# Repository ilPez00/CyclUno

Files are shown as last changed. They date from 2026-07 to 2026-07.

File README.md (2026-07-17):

# CyclUno

Cyclops dev unit on an Arduino Uno — deck edition. Two jobs, one breadboard:

1. **Cyclops dev unit** — the wearable product at breadboard scale: joystick
   + buttons + SPI TFT + LEDs, wired to the brain over USB serial. No WiFi/BT —
   the cable substitutes the radio while exercising the exact same v2 frame
   protocol and the exact same brain pipeline (transcriber → extractor →
   notes → HUD frames).
2. **aion control deck** — the physical console for the
   [aion](https://github.com/ilPez00/aion) cockpit TUI: two thumb
   joysticks, four face buttons, a mode switch. In AION mode the deck
   navigates the cockpit one-handed; in APP mode it becomes a Linux gamepad
   (uinput "CyclUno Pad") driving whatever program aion spawned. The SPI TFT
   mirrors aion status. Jarvis, but with detents.

The cyclops brain side (SerialLink, `demo_cycluno.py`, bash TUI) lives in the
[cyclops](https://github.com/ilPez00/cyclops-wearable) repo; the aion deck
host side lives in aion (`src/aion/deck/`). This repo is the firmware only.
Wire protocol: `include/cyclops_shared.h` (kept in sync with cyclops
`firmware/lib/cyclops_shared`); input-event payloads: `include/deck.h`
(pinned byte-for-byte to aion's `deck/protocol.py` by `test/test_deck.cpp`).

## Why an Uno when the XIAO exists
- Input bring-up without risking the wearable board.
- The ATmega328P's 2 KB SRAM forces the lean-HUD discipline
  (`sizeof(UnoHud)` gated < 400 B by the host tests).
- Anything proven here (input handling, frame flow, pipeline) transfers
  upstream unchanged, because the wire protocol is shared.

## Wiring

deck wiring

Full assembly guide — BOM, step-by-step order (each step leaves a working
unit), rules the wiring relies on, troubleshooting: **[docs/WIRING.md](docs/WIRING.md)**.

Quick pin map: confirmed 128×128 SPI TFT (ST7735, 1.44 in)
TFT D11 MOSI/SDA · D13 SCK/SCL · D10 CS · D9 DC · RES→3.3V via 10k · BL→3.3V/VCC per module
joy1 A0/A1+D4 · joy2 A2/A3+D8 · B D5 · MODE D2 · X D3 · Y D12 · LEDs D6/D7 ·
APP LED A4 (external; D13 is now TFT clock). Everything beyond joy1 + B is optional: unwired pins
read as unpressed (internal pullups) and the unit degrades to the original
single-stick HUD.

console layout

### Controls — AION mode (A4 LED off)
Local HUD: **stick 1 up/down** scrolls · **stick 1 right / SW** = A (REC
toggle on HOME, select in MENU) · **stick 1 left / button B** = menu/back.
Forwarded to the aion cockpit: **joy2** = navigate workspaces · **X** = pause ·
**Y** = cancel · **stick 2 click** = activate.

### Controls — APP mode (MODE button toggles, A4 LED on)
The deck is a gamepad: **stick 2** = analog axes · **A/B/X/Y + both stick
clicks + wheel click** = buttons · **joy2** = navigate. aion exposes it as a
uinput device named "CyclUno Pad"; spawn a program (`run app mpv …`) and play.

Keep both sticks at rest during boot — those readings become the calibrated
centers. If a direction feels flipped for your module's mounting, set
`JOY_FLIP_Y` / `JOY_FLIP_X` in `src/main.cpp`.

## Build + flash
```
make test     # host gate: HUD logic + joystick nav + deck logic, plain g++
make build    # pio run -e cycluno
make flash    # pio run -e cycluno -t upload
```

## Run the wired brain
From the cyclops repo:
```
python3 demo_cycluno.py       # auto-picks /dev/ttyACM*|ttyUSB*
```
Press **A** on the unit: the driver "transcribes" the next prerecorded take
through the real pipeline and streams the extracted notes back as NOTE frames
onto the SPI TFT.

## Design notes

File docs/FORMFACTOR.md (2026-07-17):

# CyclUno — Form Factor Spec (aion control deck)

Design thesis for the physical enclosure. Grounded in the aion cockpit nav
model (see `aion/src/aion/`) and HCI precedent for split dual-thumbstick
one-handed consoles (Steam Controller / Xbox Adaptive / FragChuck lineage).

## 1. What the deck IS

CyclUno is the **aion control deck**: a two-thumb, one-handed cockpit console.
- **joy1 (left thumb)** = primary navigation: up/down scroll lists, left/right (or
  SW click) = switch workspace (13 workspaces, wraps modulo).
- **joy2 (right thumb)** = activate/context in AION mode; analog axes in APP mode
  (uinput "CyclUno Pad" gamepad).
- **Buttons**: A=activate/REC, B=back/menu, MODE=AION⇄APP toggle, X/Y=context.
- **OLED (128×128, 16×16 text grid)** = status compass: always show WORKSPACE
  NAME + 1-line context (top row), since 13 workspaces need constant orientation.
- **MODE** must be a physical slide/rocker with detent, NOT a held button
  (context flip you can feel without looking).
  **RESOLVED (2026-07-17, research-backed):** part = **MTS-103** mini toggle,
  SPDT ON-OFF-ON (AION/OFF/APP), panel-mount M6×0.75 bushing + 2.4 mm keyway
  (see docs/reference/palm-deck-research.md §4). Solder-lug part — the
  breadboard dev unit keeps the momentary button on D2. Firmware 3-pos read
  (D2 + A5 INPUT_PULLUP, center-off = neither low) is DEFERRED: mode codes are
  pinned byte-for-byte to aion's deck/protocol.py (0=AION 1=APP only), so an
  OFF state is a cross-repo protocol change to coordinate with aion first.

## 2. Ergonomic rules (from HCI precedent)

1. **Offset symmetric thumbsticks, not collinear.** Steam/Xbox layout is proven
   best for simultaneous dual-thumb use without hand cramp. Two HW-504 sticks
   sit at ~45° offset (left-lower, right-upper), like a Steam Controller —
   NOT side-by-side flat.
2. **Thumbs own the whole interaction.** joy1 does list-scroll AND workspace-switch;
   it needs a click (SW=activate) + 4 directions. No finger-reassignment mid-flow.
3. **Mode = detent rocker.** AION⇄APP is a context flip; a 3-pos rocker
   (AION / OFF / APP) you feel, prevents accidental gamepad-vs-cockpit mode.
4. **OLED as status compass, not a screen.** 128×128 = 16×16 text. Top row =
   workspace + context. This is the "where am I" anchor.
5. **One-handed grip envelope.** Fits a relaxed palm, both thumbs on sticks.
   Target ~90–110mm wide, ~60–70mm deep, contoured to palm.

## 3. Highest-frequency action = workspace switch

13 workspaces (desktop, models, tasks, agent, memory, vault, sys, hermes,
skills, projects, term, swarm, settings). joy1-left/right → `switch_workspace`
is the most-used nav action — keep it on the PRIMARY thumb, low-friction,
non-mode. Current protocol already maps joy1 L/R → switch_workspace. **Keep it.**

## 4. Recommended form factor — TIER A: "Palm Deck"

Evolve the enclosure from a rectangular breadboard box into a contoured controller:

- Contoured underside (fits palm); flat-ish top face.
- **Offset thumbsticks**: left stick lower-left ~30° rake, right stick upper-right.
- **MODE rocker** (3-pos AION/OFF/APP) with detent, on the top edge.
- **OLED** top-center as status compass.
- **4 buttons as a diamond** under the right-thumb arc: A bottom, B left, X right, Y top.
- Grip edges rounded (R~15mm corners), not a sharp rectangle.

## 5. TIER B (interim): "Dockable Slab"

What v0.2 already is, upgraded:
- Keep 94×66 rectangular case + breadboard standoffs.
- Rake the two stick cutouts (not parallel).
- Add MODE rocker slot.
- OLED top-row workspace label (cutout already in v0.1).

Good for desktop; less ideal handheld. This is the pragmatic step while Tier A
is prototyped.

## 6. CAD evolution map

| Ver | Form | State |
|-----|---|---|
| v0.1 | rectangular slab, OLED+stick+button holes | built, saved |
| v0.2 | slab + 4 standoffs + screw-on lid | built, committed (14bae91) |
| v0.3 | TIER B slab: raked sticks + MODE slot + rounded grip (coordinate-placed, NOT ergo-derived) | built, committed (ae5e340) — DEV ENCLOSURE, not final form |
| v0.4 | TIER A Palm Deck — layout DERIVED from hand envelope (thumb-pad centers, sight-line OLED, detent MODE) | built, committed — hand metrics are AVG (parameterize w/ real) |
| v0.5 | contoured shell + real-component holes | built, committed (b122cbe) |
| v0.6 | thumb wells + counterbores + Uno standoffs | script only — never produced an FCStd: face-loft returned a Shell (booleans die), no `saveAs`, layout cut in the wrong quadrant, stick rake passed radians to a degrees API, buttons landed inside the joy2 well, display pocket still OLED |
| v0.7 | TFT-era redesign: solid loft + hollow-by-cut, first-quadrant layout, offset sticks (rule 1), button diamond clear of wells, real Uno drill pattern on 6 mm floor standoffs, USB-B + jack wall cutouts, square ST7735 window, saveAs | built, FCStd saved — TFT module dims are PLACEHOLDERS, measure before print |
| v0.8–v10 | split Tray + TopShell, dims from pulled STEP models, counterbored top-down screws (concurrent Hermes line) | built, committed — tray outer is wider than the shell footprint at z=0, halves don't mate yet |
| v11 | v10 + research-verified dims: MSP1443 landscape TFT pocket (29.7×43.36 PCB, 26.2×27.2 active window), MTS-103 M6+keyway MODE mount, FDM hole sizing (self-tap −0.25 / clearance +0.25 dia, wider bosses) | built, FCStd saved — TFT post pattern still UNDOCUMENTED by vendor, measure; tray/shell mate still open |

> **Honesty note (v0.3):** the cutouts are coordinate-placed against a rectangle, not
> derived from thumb-reach. It protects the breadboard and proves the cutout *set*,
> but it is NOT ergonomic. v0.4 must derive hole positions from a palm-grip
> envelope, not from `makeBox` guesses.

## 7. Open fits to verify (before print)

- Real stacked height of breadboard + Uno (standoff height depends on it).
- Exact control positions once components are placed on the breadboard.
- HW-504 stick shaft travel vs rake angle (rake changes shaft clearance).
- OLED module bezel vs cutout (30×30 window in v0.1).

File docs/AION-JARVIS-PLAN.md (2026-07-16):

# AION → JARVIS — Full AI-OS Transformation

Github: `ilPez00/aion` + `ilPez00/CyclUno`
Scope: TUI cockpit + Arduino physical deck → proactive voice-interactive AI companion

---

## DEEPSEARCH — Codebase Survey

### Two layers, one protocol

| Layer | Root | Tech | Role |
|---|---|---|---|
| aion TUI | `/home/gio/aion/src/aion/` | Python + Textual | Cockpit, Intent routing, AI harnesses, voice, stats |
| CyclUno deck | `/home/gio/CyclUno/` | Arduino C++ (ATmega328P) | Physical input (2 joysticks, 6 buttons), OLED, LEDs |

Wire protocol: v2 framing (`0xAA 0x55 | len16 | type | payload | crc16`), shared header `cyclops_shared.h`.

### Current state

| Dimension | What exists | Gap vs Jarvis |
|---|---|---|
| Voice input | `VoiceInput` in `input.py` — offline faster-whisper STT, energy-VAD, intent parse | **Output only** — no TTS. Can't speak back. No personality. |
| Visuals | `UnoHud` — 16×16 text grid on 128x128 OLED. 8x8 font, no graphics | **No animation.** Text rows only. No arcs, icons, transitions. |
| AI | Multi-harness: DemoHarness, ShellHarness, CyclopsHarness(stub), AppHarness | **Reactive only.** Wait for user command. No proactive suggestions. |
| Personality | Menu items: "Notes", "Ask agent", "Home". Toast: "REC on", "REC off". | **No character.** Everything functional. No wit, no soul. |
| System integration | AppHarness (spawn + SIGSTOP/SIGCONT). TelemetryHarness (nvidia-smi/ollama polls). | **Reactive.** No proactive system monitoring. No environment awareness. |
| Memory | `MemoryStore` — flat fact list. Substring query. Persisted to JSON. | **No episodic memory.** No auto-logging of events. Can't answer "what happened today?" |
| Hardware | ATmega328P (2 KB SRAM, 32 KB flash). 56% RAM used by `UnoHud` (<400B gated). | **RAM locked.** No framebuffer graphics. No audio. No room for animations. |

### Key files

| File | Lines | Role |
|---|---|---|
| `aion/src/aion/ui/app.py` | 350 | Textual cockpit — compose, render, key bindings, bus subscription |
| `aion/src/aion/store.py` | 231 | Intent handler + state machine ("brain") |
| `aion/src/aion/input.py` | 391 | All input: keyboard map, joystick (evdev), voice (faster-whisper), deck serial |
| `aion/src/aion/core.py` | 271 | Bus, Intent, TaskRegistry, SessionStore, Config |
| `aion/src/aion/harnesses.py` | 386 | AI backend abstraction — 6 harness types |
| `aion/src/aion/deck/link.py` | 130 | Serial transport to CyclUno (background thread) |
| `aion/src/aion/deck/protocol.py` | 126 | Wire protocol encode/decode, InputEvent |
| `aion/src/aion/memory.py` | 71 | Flat fact store, persist to JSON |
| `CyclUno/src/main.cpp` | 263 | Firmware main — loop, polling, HUD rendering, serial framing |
| `CyclUno/include/cycluno.h` | 211 | `UnoHud` — state machine, RowSink, 3 modes (HOME/NOTES/MENU) |
| `CyclUno/include/deck.h` | 82 | Input event packing, `RawAxisStream` (APP mode) |
| `CyclUno/include/joynav.h` | 61 | Joystick deadzone + auto-repeat logic |
| `CyclUno/include/cyclops_shared.h` | 155 | Shared: CRC16, `FrameDecoder`, `DisplayModel`, `UiState` |

### Risks (premortem)

| Risk | Impact | Mitigation |
|---|---|---|
| R1: ATmega328P RAM overflow (2 KB) | Adding graphics, animation state, audio buffers crashes firmware | MCU upgrade (ESP32-S3/RP2040) before Phase 2. Uno stays dev target. |
| R2: TTS latency > 1.5s breaks illusion | "Dead air" before response kills Jarvis feel. User loses trust. | Streaming/chunked TTS. Pre-warm model on boot. Show "thinking" indicator. Premium: ElevenLabs streaming. |
| R3: Proactive agent annoys user | Suggesting unprompted = interruptive, not helpful | Strict priority (user-safety > system-crit > suggestion). Mute/snooze. Learn user patterns. |
| R4: Personality reads fake | Witty one-liners in TUI = cringey, not Jarvis-like | Personality through *behavior* first (speed, anticipation, conciseness). Wit last. |
| R5: Scope creep kills delivery | Nothing ships if every phase is "perfect" | 3 strict phases. Each gates on previous. Phase 1 ships in days. |
| R6: aion GitHub public? | Repo returned 404. May not push upstream. | Work from local clone. Verify remote access before pushing. Fallback: local-only commits. |
| R7: Attentional user base | User has many concurrent projects. Expects fast results, may orphan. | Ship Quick Wins in 1-2 days to demonstrate value. Each phase must demonstrate value independently to maintain momentum. |
| R8: Cache poisoning risk | Old persona strings may linger in TUI text. Template substitution could leave stale markers. | Covering memory, persona, and template tests. Explicit TUI text regeneration on persona change. |

---

## FACTORY LOOP — Execution Plan

### Premortem (before any code)

- **Break CI**: Existing `make test` + `pytest tests/` must still pass. Any new code must add tests.
- **Corrupt git**: Never `git add -A`. Stage specific files only. One commit per logical unit.
- **Overwrite user work**: Verify `git status -s` before write. Stash user edits if present.
- **Stale toolchain**: `pip install -e ".[deck,voice,dev]"` in aion venv. `make test` for CyclUno (g++ host gate).
- **Rollback**: Every commit = revert point. `git reset --hard <sha>` if a step breaks.
- **Permission**: User approved batch scope above. No re-prompt per command. Smart-approve routine edits.

### Batch permission scope (asked once)

This plan covers all 3 phases. Permission covers:
- Read/write all files in `/home/gio/aion/src/aion/` and `/home/gio/CyclUno/` and `/home/gio/CyclUno/docs/`
- Run `make test`, `pytest`, `pip install`, `python3 -m aion.ui.app` (headless smoke)
- `git commit` + `git push` per cycle
- No: sudo/-H/-S installs, hardware flash without confirm

---

## PHASE 1 — Voice Loop + Personality (ship in days)

Goal: aion talks back, has a character, feels alive.

### Cycle 1.1: TTS engine

- **Write** `/home/gio/aion/src/aion/voice/output.py`
- Class `VoiceOutput`: wraps `edge-tts` (zero dep friction, fast, British voice available). Async `say(text)`. Fallback: `pyttsx3` if edge-tts missing. No-op if no audio device.
- Add optional dep `[voice-tts]` = `edge-tts` to `pyproject.toml`
- Test: `python -c "from aion.voice.output import VoiceOutput; import asyncio; asyncio.run(VoiceOutput().say('Hello, sir.'))"` → audio plays.
- Verify: `pytest tests/` still passes. No new warnings.

### Cycle 1.2: Personality module

- **Write** `/home/gio/aion/src/aion/voice/persona.py`
- `Persona` class: maps event type → response string with character.
- Patterns:
  - task DONE → "Done, sir." / "Finished. Anything else?" / "As requested."
  - task FAILED → "Hit a snag. Let me try another approach."
  - startup → "Good [morning/afternoon/evening]. Aion online. All systems nominal."
  - idle 5m → "Standing by." (once, not repeated)
- Attributes: `verbosity` (terse/normal/chatty), `formality` (formal/casual), `name` ("aion").
- Persist persona config to `~/.aion/persona.json`.
- Config in `config/layout.json` -> `persona: { name, verbosity, formality }`.
- Test: unit tests for event→response mapping. Assert not empty, <200 chars, no unprintable chars.

### Cycle 1.3: Wire TTS into bus

- **Edit** `/home/gio/aion/src/aion/store.py` — subscribe to task state in `_on_task_event`. On DONE/FAILED/CANCELLED, emit voice event.
- **Edit** `/home/gio/aion/src/aion/ui/app.py` — on boot, init `VoiceOutput` and subscribe to voice events. Create `_on_voice(msg)` that calls `voice.say(msg.text)`.
- Rate limit: not per progress tick. Only on state transitions + significant events.
- Test: simulate task completion → verify `VoiceOutput.say()` called with persona response string.

### Cycle 1.4: Personality in TUI text

- **Edit** `/home/gio/aion/src/aion/ui/app.py` — replace bottom bar help string with character intro on boot. Replace "running: 2" with "two tasks in progress" style.
- **Edit** `/home/gio/aion/src/aion/store.py` — use personality module for status lines in history.
- Test: assert bottom bar != raw help string after 1s. Assert task count uses natural language.

### Cycle 1.5: Quick-win theme + startup

- **Edit** `config/layout.json` — add "Jarvis" theme preset (cyan `#00d4ff` accent, orange `#ff8c00` warn, deep blue `#0a1628` bg).
- **Edit** `/home/gio/aion/src/aion/ui/app.py` — on `on_mount`, print "Aion online. All systems nominal." with typing effect on bottom bar. Play startup chime via `paplay` or `aplay` (optional WAV in `~/.aion/sounds/`).
- Test: boot, see "Aion online..." in bottom bar. No crash if no audio device.

**Phase 1 gate**: user hears "Good morning. Aion online." on boot. Tasks complete with "Done, sir." spoken. TUI text matches character. All existing tests pass.

---

## PHASE 2 — Visual Richness + Proactive Behavior

Goal: deck OLED animates, TUI shows live charts, aion suggests before asked.

### Cycle 2.1: Deck MCU upgrade (ESP32-S3)

- **Write** new build target in `CyclUno/platformio.ini`: `[env:esp32s3]` using `platform = espressif32`, `board = esp32-s3-devkitc-1`.
- **Add** `CyclUno/include/cycluno_gfx.h` — graphics mode HUD alongside text `UnoHud`.
- Upgrade opens: 512 KB SRAM (vs 2 KB), 240 MHz dual-core, I2S for audio, WiFi/BLE.
- Keep backward compat: `make build` still compiles Uno target.
- Verify: `pio run -e esp32s3` compiles without error (no flash needed for gate).

### Cycle 2.2: Animated OLED UI

- **Write** `CyclUno/include/cycluno_gfx.h` — class `AnimatedHud`:
  - Progress arcs (circle that fills clockwise) for task progress
  - Smooth scroll between notes (vertical slide, not jump-cut)
  - Status icons: mic pulse when voice active, glowing REC dot
  - Fade transitions between HOME/NOTES/MENU modes
  - Boot animation: "AION" draws in, glow pulse, fade to HUD
  - U8g2 framebuffer mode (not tile-based text)
- **Edit** `CyclUno/src/main.cpp` — switch renderer based on build target (`#ifdef ESP32` block).
- Verify: host-gate test feeds frame data, asserts pixel buffer changes between renders.

### Cycle 2.3: System tones on deck

- **Add** piezo buzzer pin (D9) to BOM for ESP32 build.
- **Edit** `CyclUno/src/main.cpp` — play tones:
  - Power-on: rising two-note chime (440Hz→880Hz, 100ms each)
  - Task complete: single 660Hz 80ms
  - Error: low 220Hz 200ms
  - Mode switch: short click 1kHz 10ms
- Config: `SoundProfile` enum (normal/silent/loud). Set in firmware build flags.
- Verify: tone patterns produce expected frequency + timing (oscilloscope or manual listen).

### Cycle 2.4: Rich TUI sparklines + themes

- **Edit** `/home/gio/aion/src/aion/ui/app.py`:
  - Right rail: live sparkline for task throughput (last 60s, unicode braille characters)
  - VRAM usage bar: green→yellow→red gradient
  - Task progress: braille fill for sub-character resolution
  - Header clock: show seconds ticking
  - Theme presets: "Jarvis" (cyan/orange), "Night" (muted blues), "Hologram" (green/cyan)
- Test: sparkline updates without widget remount (performance regression guard).

### Cycle 2.5: Proactive engine

- **Write** `/home/gio/aion/src/aion/proactive.py` — class `ProactiveEngine`:
  - Timer loop (every 30s). Watch conditions:
    - CPU > 90% for 30s → "System under load. Pause background?"
    - 12+ facts without query → "12 facts accumulated. Summarize?"
    - 5min no input → "Standing by." (once)
    - Task chain: finished + queued → "Next task ready. Start?"
  - Strict debounce: max 1 proactive event per 60s. User input resets idle.
  - Quiet mode: suppress all proactive. Config in `config/layout.json`.
- **Edit** `/home/gio/aion/src/aion/store.py` — connect proactive engine to bus.
- **Edit** `/home/gio/aion/src/aion/ui/app.py` — display proactive suggestions as toasts.
- Test: mock conditions, assert correct suggestion fires. Quiet mode suppresses all.

**Phase 2 gate**: OLED shows animated arcs, smooth scroll, boot logo. TUI has live sparkline + VRAM bar. Proactive engine offers context suggestions without being annoying. All Phase 1 + Phase 2 tests pass.

---

## PHASE 3 — Integration + Memory + Polish

Goal: system awareness, rich memory, wake word, settings hub, cinematic startup.

### Cycle 3.1: System monitoring harness

- **Edit** `/home/gio/aion/src/aion/harnesses.py` — upgrade `TelemetryHarness` to `SystemHarness`:
  - CPU per-core usage, load average
  - RAM used/total/available
  - Disk I/O, space usage
  - Network throughput (tx/rx per interface)
  - Running processes (count + top 3 by CPU)
  - Battery level (if laptop)
- Output: stats published on bus every 5s. Right rail shows live SYNC panel.
- Test: mock `/proc` fixtures, assert correct stat parsing. Graceful degrade when `/proc` inaccessible.

### Cycle 3.2: Enhanced memory (episodic + semantic)

- **Edit** `/home/gio/aion/src/aion/memory.py`:
  - Episodic: auto-log significant events to `~/.aion/episodes/YYYY-MM-DD.jsonl`.
    - Schema: `{ts, type:"task_done"|"voice_cmd"|"note_added", text, detail:{}}`
  - Semantic: facts (`note`) keep existing behavior. Add tags support (`#urgent`).
  - Recall: `mem query` searches both episodic and semantic stores. Results with timestamp + source tag.
  - Auto-archive: facts > 90d move to `~/.aion/memory.archive.json`.
- Test: auto-log fires on task done. Search returns both episodic + semantic results. Archive triggers correctly.

### Cycle 3.3: Voice personality polish

- **Edit** `/home/gio/aion/src/aion/voice/output.py`:
  - SSML support for emotion/emphasis in TTS (`<emphasis level="strong">`, `<prosody rate="slow">`).
  - Multiple piper-tts voice variants: one neutral, one alert (higher pitch/rate).
- **Edit** `/home/gio/aion/src/aion/voice/input.py` (`VoiceInput`):
  - Add wake word "Aion..." via Porcupine or openWakeWord.
  - Wake word activates listen mode without pressing `v`.
  - Interrupt: if aion speaks and user speaks, stop TTS + start listening.
- **Edit** deck OLED: show mic icon with animation when voice active.
- Test: wake word triggers listen. Interrupt stops TTS mid-word.

### Cycle 3.4: Settings hub

- **Write** `/home/gio/aion/src/aion/ui/settings_screen.py` — new workspace "Settings":
  - Voice: TTS speed (0.5x-2x), voice gender (male/female), volume, wake word on/off, quiet hours (start/end)
  - Personality: verbosity (terse/normal/chatty), formality (formal/casual), name
  - Proactive: toggle per category (system/memory/idle)
  - Theme: dropdown of presets, preview applies in real-time
  - Deck: OLED brightness (0-100), animation speed (slow/normal/fast), sound profile (normal/silent/loud)
- **Edit** `/home/gio/aion/config/layout.json` — add "settings" workspace.
- **Edit** `/home/gio/aion/src/aion/store.py` — persist settings to `~/.aion/settings.json`.
- Test: load/save round-trip for every setting. Theme switch doesn't crash.

### Cycle 3.5: Cinematic startup

- **Edit** `/home/gio/aion/src/aion/ui/app.py`:
  - Boot sequence: "AI engines... online." → "Voice synthesis... calibrated." → "Memory stores... loaded." → "Control deck... linked." Each line typing effect, 300ms pause.
  - Then: "Good morning, sir. All systems nominal." (uses persona greeting).
- **Edit** `CyclUno/src/main.cpp` (or `cycluno_gfx.h`):
  - Animated "AION" logo on OLED boot: draw letter-by-letter, glow pulse, blink 2x, transition to HUD.
- **Edit** `VoiceOutput` — play startup chime at boot.
- Test: boot sequence renders without blocking UI. Deck animation finishes within 3s.

**Phase 3 gate**: Full Jarvis feel — wake word, system-aware, rich memory recall, cinematic startup, fully customizable settings. All 3 phases' tests pass.

---

## VERIFICATION GATES

### Every cycle

```bash
# aion
cd /home/gio/aion && .venv/bin/python -m pytest tests/ -v

# CyclUno host gate
cd /home/gio/CyclUno && make test

# CyclUno compile gate (both targets if ESP32 added)
cd /home/gio/CyclUno && make build && pio run -e esp32s3
```

### Phase gates

| Phase | Gate | Who verifies |
|---|---|---|
| 1 | User hears TTS. TUI shows character text. All tests pass. | dev + manual listen |
| 2 | OLED animates. TUI shows sparklines. Proactive suggestion fires. | dev + visual check |
| 3 | Wake word works. Memory recall returns episodes. Startup cinematic plays. | dev + manual |

### Manual checks per phase

- Phase 1: mouth-to-ear < 2s. Personality reads natural (not robotic/annoying).
- Phase 2: OLED animation > 15 fps perceived. Proactive: 1h usage, log all suggestions, review.
- Phase 3: wake word detection rate > 80% in quiet room. Memory recall relevant to query > 70%.

---

## COMMIT DISCIPLINE

Per factory-loop:

1. `git diff --cached --name-only` before commit — no stray files
2. One commit per logical unit (not per day)
3. Commit message: conventional commits (`feat:`, `fix:`, `refactor:`, `test:`, `docs:`)
4. `git push` only on green (all tests pass)
5. Branch per phase: `jarvis/p1`, `jarvis/p2`, `jarvis/p3`
6. No `git add -A`. Explicit paths only.

Rollback: `git reset --hard <pre-commit-sha>` if a step breaks CI or corrupts behavior.

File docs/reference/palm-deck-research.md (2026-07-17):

# Palm-deck research compendium (2026-07-17)

Deep-research harvest for the CyclUno Palm Deck redesign (case v0.7+).
Method: 5-angle web sweep → source fetch → adversarial 3-vote verification.
Two runs both hit session limits mid-verify, so only the first claims carry a
**VERIFIED 3-0** stamp; the rest are **source-cited but unverified** — treat as
strong leads, confirm against the physical part before cutting plastic.
Sources are condensed here per the cross-project research-mirror rule; URL per
claim, no verbatim doc mirrors.

## 1. Display — 1.44″ ST7735 128×128 SPI breakout

| Fact | Status | Source |
|---|---|---|
| MSP1443 PCB **29.7 × 43.36 mm**, active area **26.2 × 27.2 mm**, 128×128 | VERIFIED 3-0 | lcdwiki.com `1.44inch_SPI_Module_ST7735S_SKU:MSP1443` |
| VCC accepts 3.3–5 V, but logic IO is **3.3 V TTL** → level-shift from 5 V Uno GPIO | VERIFIED 3-0 | same |
| Manual has **no mounting-hole pattern / mechanical drawing** — measure the real module | VERIFIED 3-0 | lcdwiki MSP1443 user manual PDF |
| VCC pin can take Uno 5 V rail directly (onboard regulation) | VERIFIED 3-0 | same |
| 8-pin single-row header (VCC GND CS RESET A0 SDA SCK LED) along one edge; LED active-high, tie to 3.3 V for always-on | unverified | lcdwiki MSP1443 |
| Sibling SKU MAR1441 (Arduino shield form): PCB 31.49 × 43.95 mm, same 26.2 × 27.2 active area | unverified | lcdwiki MAR1441 |
| displaymodule.com panel: active 25.50 × 26.50 mm; bare ST7735S panel is 2.8 V — 5 V safety depends entirely on breakout circuitry | unverified | displaymodule.com DM-TFT144-399 |
| Vendor manual wires logic pins straight to 5 V Uno GPIO with no shifter (vendor practice, not proof of safety) | unverified | lcdwiki manual |

**Design consequence:** WIRING.md's level-shift rule stands (verified 3.3 V TTL
IO). Case v0.7 TFT params updated to MSP1443 dims; active-area offset within
the PCB is undocumented — measure before final print.

## 2. Thumbstick — HW-504 / KY-023

| Fact | Status | Source |
|---|---|---|
| KY-023-style module ≈ **34 × 26 × 32 mm**, four **M4** mounting holes, 5-pin header | unverified | handsontec PS2-Joystick.pdf |
| HW-504 overall ≈ 40 × 26 × 32 mm (footprint + stick height) | unverified | docs.cirkitdesigner.com HW-504 |
| Runs on 5 V; each axis rests ~2.5 V mid-rail, full swing 0–5 V — no shifting needed | unverified | handsontec |
| Joy-IT KY-023 datasheet contains **zero mechanical data** | unverified | naylampmechatronics KY-023 PDF |
| Thingiverse KY-023 mockup models place the stick's rotation point at origin, purpose-built for testing rake angles in enclosure CAD | unverified | thingiverse.com thing:7014864 |
| Two-half printed shell around KY-023 is a proven community pattern | unverified | makerworld.com model 1556892 |

**Design consequence:** no authoritative shaft-travel spec exists — the 12°
rake clearance must be validated with the Thingiverse rotation-origin mockup or
the physical part. STEP model already in `cad/components/hw504_joystick/`
(dir present, file pending).

## 3. Ergonomics — one-handed dual-stick controllers

Fetches for this angle (researchgate, access-ability.uk, instructables) died on
rate limits in both runs — **no citable claims landed**. FORMFACTOR.md §2 keeps
its Steam-Controller-lineage heuristics (offset sticks, thumb-arc diamond,
90–110 mm palm width) as design priors, not cited fact. Re-run this angle later
or validate by printed prototype.

## 4. MODE selector — 3-position part + AVR reading

| Fact | Status | Source |
|---|---|---|
| **MTS-103**: SPDT mini toggle, **ON-OFF-ON** (center detent off) — matches AION/OFF/APP | unverified | handsontec MTS103 PDF |
| Panel-mount **M6×0.75** bushing, 9.5 mm thread height, ~6 mm panel hole + optional 2.4 mm anti-rotation keyway at 6.4 mm offset | unverified | same |
| Solder-lug termination (4.7 mm spacing) — **not breadboard-friendly**, needs flying leads | unverified | same |
| Generic 3-pos slide switch = SP3T: 1 common + 3 position pins | unverified | docs.cirkitdesigner.com 3-position-switch |
| AVR pattern: each position pin `INPUT_PULLUP`, common to GND, active-low reads | unverified | same |

**Design consequence (cycle-4 decision):** breadboard dev unit keeps the
momentary MODE button on D2 (MTS-103 can't sit in a breadboard). The Palm Deck
enclosure adopts the MTS-103: case v0.7 MODE cutout is now an M6 hole +
keyway. Firmware 3-pos support (D2 + A5, both `INPUT_PULLUP`, center-off =
neither low) is **deferred**: the input-event protocol is pinned byte-for-byte
to aion's `deck/protocol.py` (mode codes 0/1 only), so adding an OFF state is
a cross-repo change to coordinate with aion first.

## 5. FDM enclosure practice

| Fact | Status | Source |
|---|---|---|
| Min wall 2 mm (CyclUno's 2.5 mm OK) | unverified | hubs.com enclosure guide |
| Component cavities: +0.5 mm clearance all around | unverified | same |
| Screw holes: clearance = nominal +0.25 mm dia; self-tap = nominal −0.25 mm dia | unverified | same |
| Boss wall ≥ 1× hole dia (M3 boss ≈ 3 mm surrounding wall); ribs 75–80 % of wall | unverified | same |

**Design consequence:** case v0.7 updated — standoff self-tap holes 2.75 mm dia,
lid clearance holes 3.25 mm dia, standoff bosses widened to meet the 1×-dia
rule, pockets carry 0.5 mm clearance.

## Rerun note

Verification infra hit session limits twice (11:10 + 16:30 resets). 4 claims
verified, ~20 cited-unverified, ergonomics angle empty. If a claim here turns
load-bearing, re-verify it manually against the linked source.

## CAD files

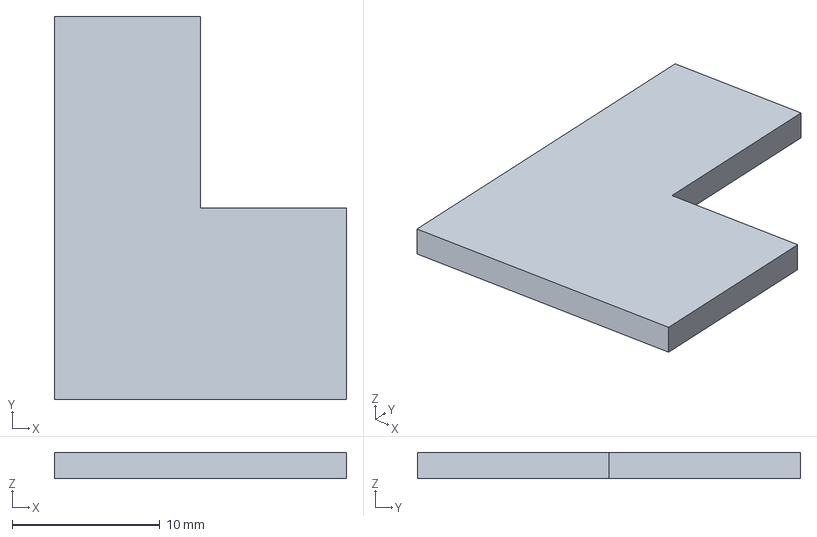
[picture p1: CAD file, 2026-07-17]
cad/components/arduino_uno_r3/Arduino_Uno.step
19.7 x 25.9 x 1.78 mm

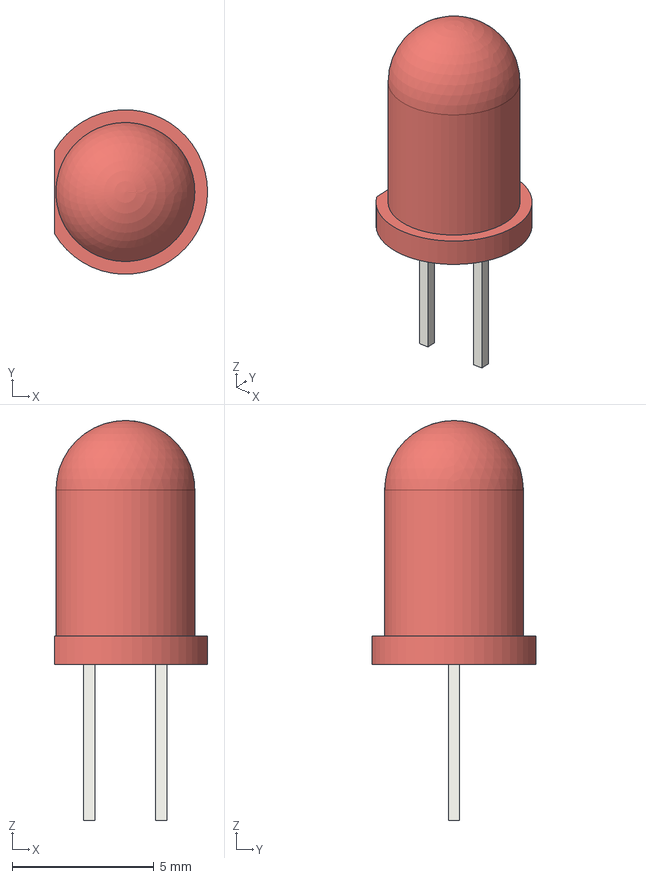
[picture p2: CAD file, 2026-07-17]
cad/components/led_5mm/LED_D5.0mm.step
5.40 x 5.79 x 14.1 mm

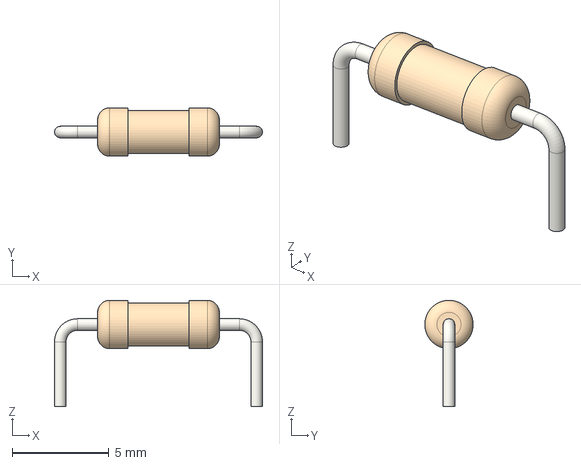
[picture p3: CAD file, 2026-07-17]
cad/components/resistor_axial/R_Axial_DIN0207_L6.3mm_D2.5mm_P10.16mm_Horizontal.step
10.8 x 2.50 x 5.50 mm

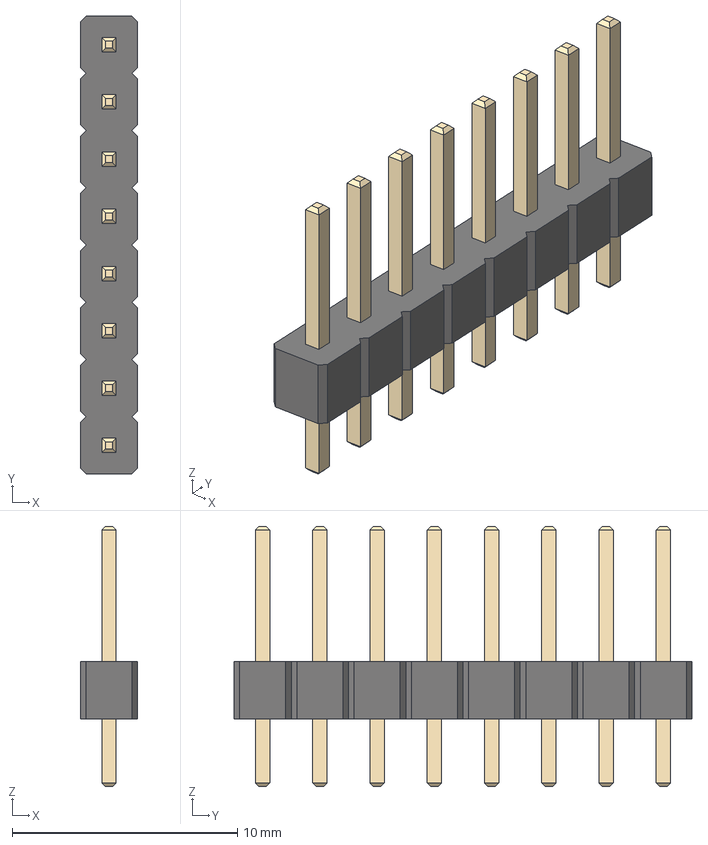
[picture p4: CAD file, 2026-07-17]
cad/components/st7735_144/PinHeader_1x08_P2.54mm_Vertical.step
2.54 x 20.3 x 11.5 mm

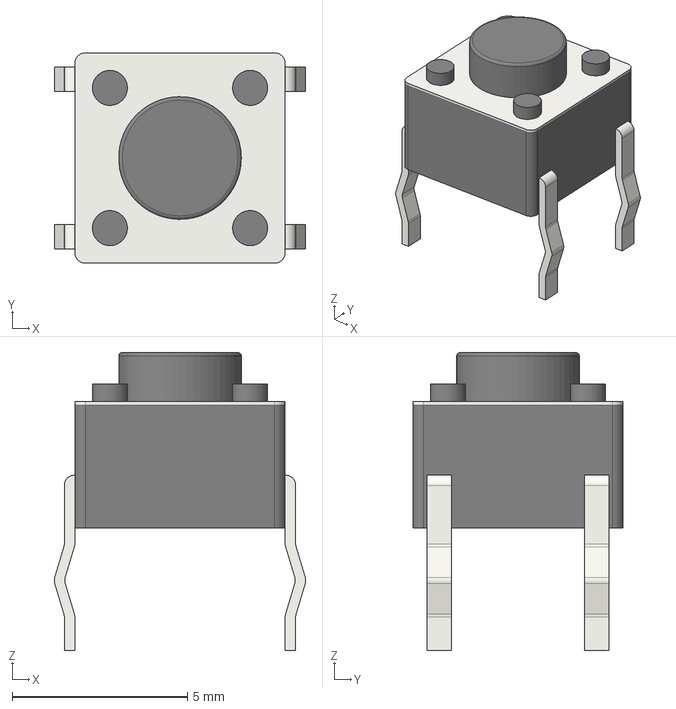
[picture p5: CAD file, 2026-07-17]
cad/components/tact_switch_6x6x5/SW_PUSH_6mm_H5mm.step
7.17 x 6.00 x 8.50 mm

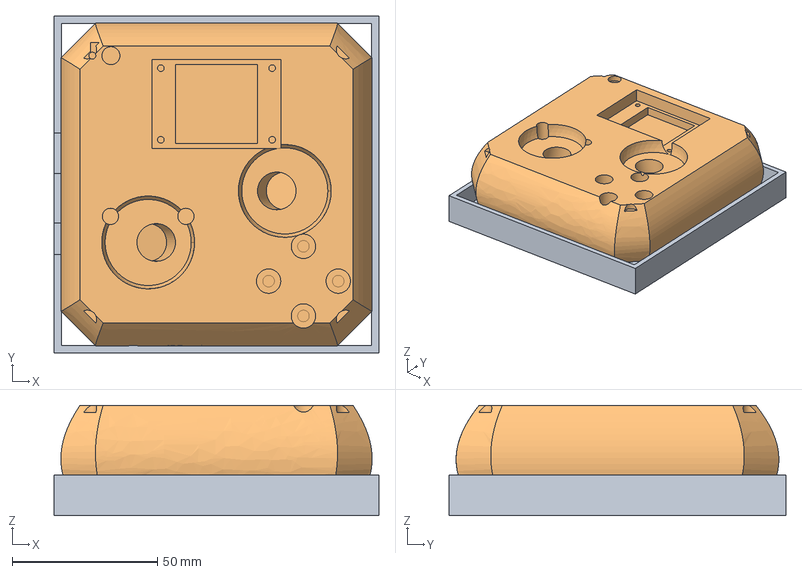
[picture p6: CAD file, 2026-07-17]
cad/cycluno_case/CyclUnoCase_v11.FCStd
112.0 x 116.0 x 38.0 mm
Tray
TopShell

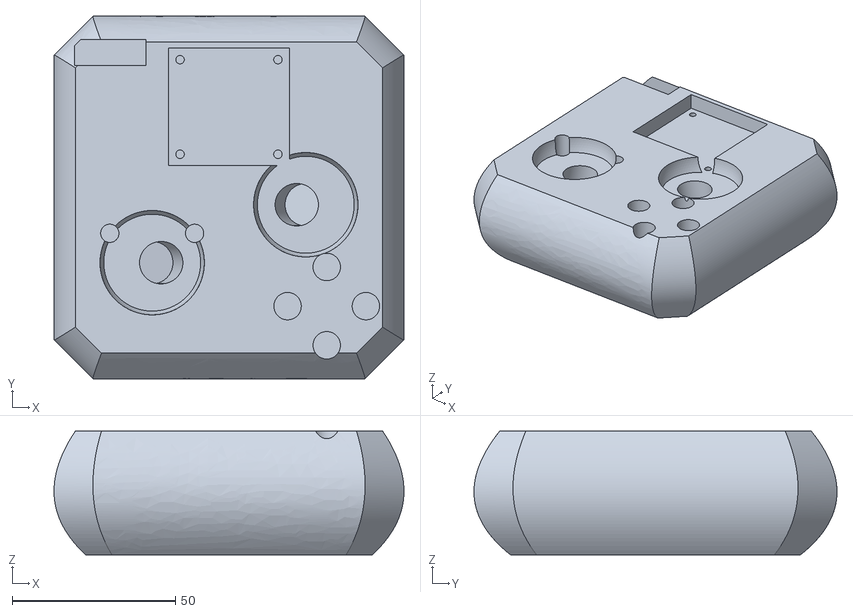
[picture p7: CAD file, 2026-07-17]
cad/cycluno_case/TopShell.stl
107.3 x 111.3 x 38.0

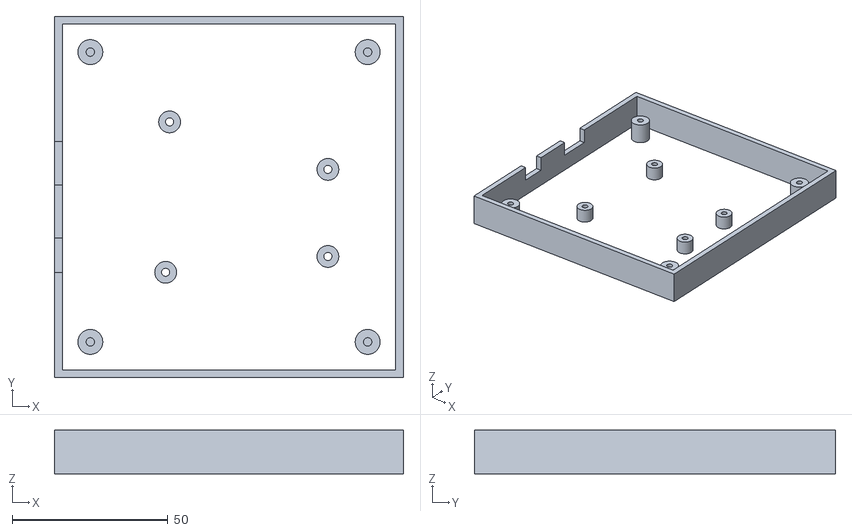
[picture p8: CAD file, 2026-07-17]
cad/cycluno_case/Tray.stl
112.0 x 116.0 x 14.0

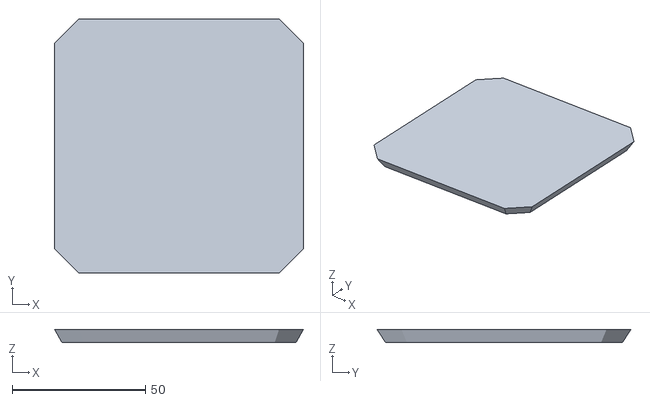
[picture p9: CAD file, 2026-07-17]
cad/cycluno_case/Lid_v09.stl
93.4 x 95.3 x 5.00

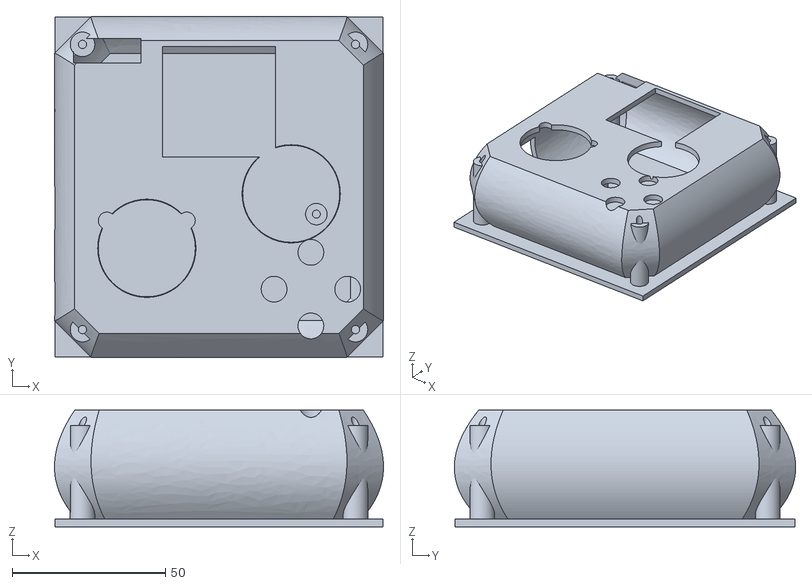
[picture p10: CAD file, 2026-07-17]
cad/cycluno_case/Base_v09.stl
107.3 x 111.3 x 38.0

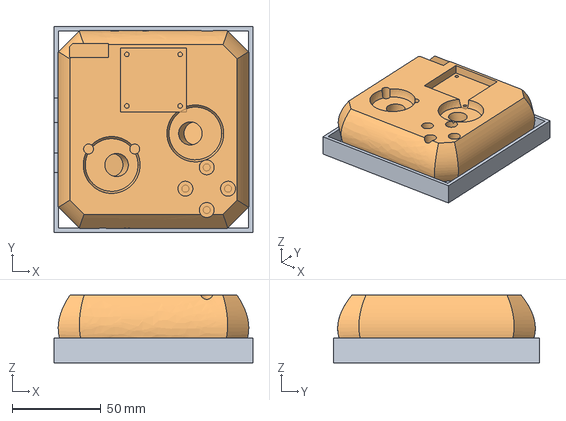
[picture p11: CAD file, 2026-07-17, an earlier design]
cad/cycluno_case/CyclUnoCase_v10.FCStd
112.0 x 116.0 x 38.0 mm
Tray
TopShell

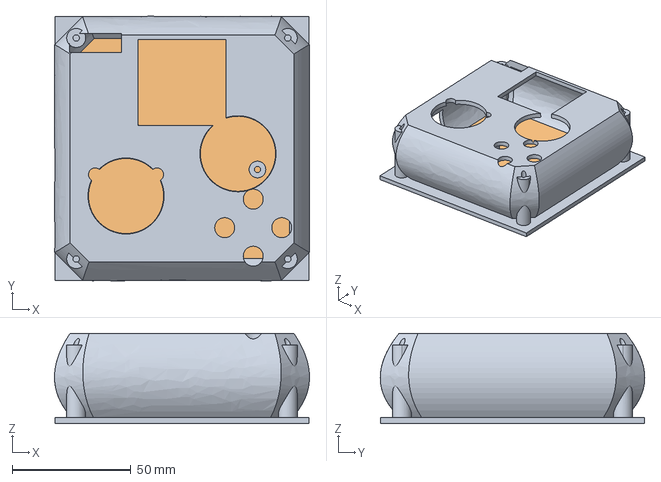
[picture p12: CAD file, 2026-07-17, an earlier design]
cad/cycluno_case/CyclUnoCase_v09.FCStd
107.3 x 111.3 x 38.0 mm
Base_v09
Lid_v09

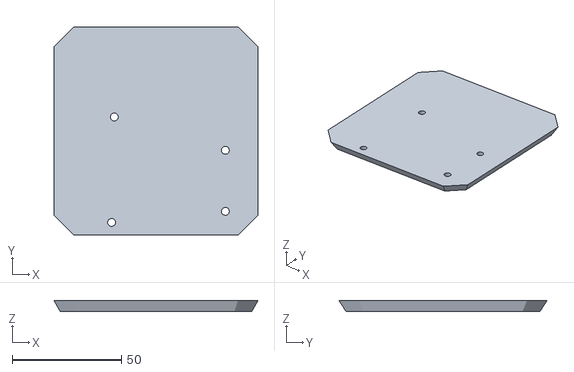
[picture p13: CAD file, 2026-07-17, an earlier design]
cad/cycluno_case/Lid_v08.stl
93.4 x 95.3 x 5.00

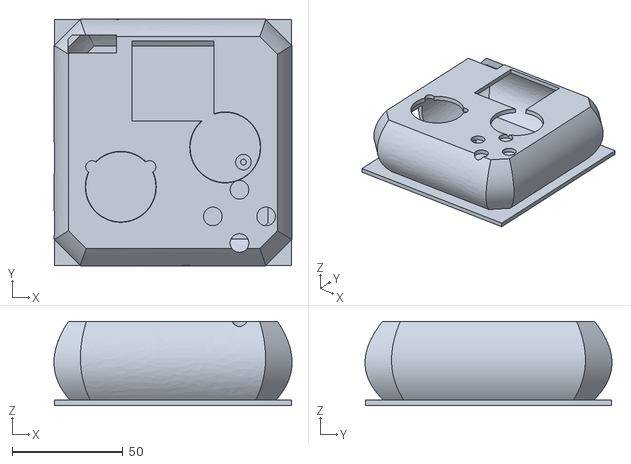
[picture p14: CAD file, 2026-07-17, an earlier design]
cad/cycluno_case/Base_v08.stl
107.3 x 111.3 x 38.0

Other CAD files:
cad/cycluno_case/CyclUnoCase_v08.FCStd
cad/cycluno_case/CyclUnoCase_v07.FCStd
cad/cycluno_case/CyclUnoCase_v03.FCStd
cad/cycluno_case/CyclUnoCase_v05.FCStd
cad/cycluno_case/CyclUnoCase_v02.FCStd
cad/cycluno_case/CyclUnoCase_v04.FCStd

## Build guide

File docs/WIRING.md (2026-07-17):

# CyclUno deck — SPI 128×128 TFT assembly & wiring

CyclUno targets the connected display: a **confirmed 128×128 SPI TFT with an ST7735 controller** (common 1.44-inch module). Its exposed `RES`, `DC`, `CS`, and `BL` pins mean this is not the former I2C OLED design. The sketch uses hardware SPI and `Adafruit_ST7735`.

## Critical electrical rule

An Arduino Uno is **5 V logic**. Most bare TFT panels are **3.3 V-only**, both power and signal.

- Feed TFT **VCC from 3.3 V**, unless its breakout explicitly says `5V`, `5V tolerant`, or documents regulator/level shifting.
- Feed `SCK`, `MOSI`, `CS`, and `DC` through a proper 5 V → 3.3 V level shifter unless board documentation explicitly guarantees 5 V-safe inputs.
- Join all grounds: Uno GND ↔ level-shifter GND ↔ TFT GND.
- Never power a 3.3 V-only panel from Uno 5 V.

## Display wiring

| TFT label | Connect to | Meaning |
|---|---|---|
| GND | Uno GND | common ground |
| VCC | 3.3 V* | panel logic/power |
| SCL / SCK / CLK | Uno D13 via level shifter* | SPI clock |
| SDA / MOSI / DIN | Uno D11 via level shifter* | SPI data to TFT |
| CS | Uno D10 via level shifter* | chip select |
| DC / A0 | Uno D9 via level shifter* | data/command select |
| RES / RST | 3.3 V through 10 kΩ | reset held released; **never floating** |
| BL / LED | 3.3 V / VCC only as module specifies | backlight enable/power |

*Level shifting is mandatory unless the breakout explicitly guarantees 5 V-safe signal inputs.

`BL` is not a Uno GPIO here. Most TFT breakouts include its LED resistor, so use the board-specified VCC/3.3 V rail. If BL is a bare LED input, use its datasheet-specified resistor; never assume it is safe at 5 V.

## CyclUno pin map

| Signal | Uno pin |
|---|---:|
| TFT MOSI / SDA | D11 |
| TFT SCK / SCL | D13 |
| TFT CS | D10 |
| TFT DC | D9 |
| TFT RES | no Uno pin; 3.3 V via 10 kΩ |
| TFT BL | 3.3 V/VCC per board |
| Joy1 VRy / VRx / SW | A0 / A1 / D4 |
| Joy2 VRy / VRx / SW | A2 / A3 / D8 |
| Button B | D5 |
| Button MODE | D2 |
| Button X | D3 |
| Button Y | D12 |
| REC / LINK LEDs | D6 / D7 |
| APP LED | A4 external (D13 is TFT clock; do not use its onboard LED as a mode indicator) |

The display consumes D9/D10/D11/D13; MODE and X move from the old layout to **D2/D3**. Buttons wire from their listed pin to GND: firmware uses `INPUT_PULLUP`.

## Bring-up order

1. Wire TFT GND, safe 3.3 V, then SPI/control lines. Keep SPI wiring short.
2. Add `RES → 10 kΩ → 3.3 V`.
3. Wire BL only after checking the module label/datasheet.
4. Flash: `make build && make flash`.
5. Expect status HUD. If blank, recheck common ground, safe voltage/level shifting, and controller identity.
6. Add joy1, B, LEDs, joy2, then MODE/X/Y.

## Build

```bash
make test
make build
make flash
```

## Troubleshooting

| Symptom | Check |
|---|---|
| Blank but backlight on | SCK D13, MOSI D11, CS D10, DC D9; common GND; RES pull-up; correct ST7735 controller |
| White / unstable screen | 5 V signal risk or no level shifting; power down and verify voltage rating |
| Lit, garbled display | controller is not ST7735 or SPI labels swapped |
| No backlight | BL behavior differs by breakout; consult board docs; do not inject 5 V |
| MODE/X do nothing | They moved to D2/D3 |

The former I2C OLED layout (A4/A5, SSD1327/SH1107) is removed from this firmware revision.

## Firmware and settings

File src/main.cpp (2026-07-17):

// CyclUno — Cyclops dev unit on an Arduino Uno, deck edition.
//
// Hardware:
//   128x128 SPI TFT (common ST7735 1.44 in): D11=MOSI, D13=SCK, D10=CS, D9=DC.
//   RES is externally pulled to 3.3 V via 10 kOhm; use level shifting unless
//   the TFT breakout explicitly marks its inputs 5 V-safe.
//   HW-504 joystick 1 (nav):  VRy=A0, VRx=A1, SW=D4 (to GND, internal pullup)
//   HW-504 joystick 2 (app):  VRy=A2, VRx=A3, SW=D8

//   buttons: B/back=D5, MODE=D2, X=D3, Y=D12
//   LEDs: REC=D6, link=D7, APP-mode=A4 (external; D13 is the SPI clock)
//
// Two personalities (MODE button toggles, A4 LED shows APP):
//   AION mode — joy1 + A/B drive the local HUD; joy2, X/Y are
//     forwarded to the host as MSG_INPUT_EVENT frames (aion turns them into
//     cockpit navigation: joy2=workspaces).
//   APP mode — local HUD input is suspended ("APP PAD" banner); joy2 raw
//     axes stream to the host, every face button forwards press+release, the
//     aion exposes it all as a uinput gamepad
//     ("CyclUno Pad") that drives whatever program aion spawned.
//
// Link: USB serial @115200 speaking the shared v2 framing — the same frames
// the XIAO speaks over BLE, so the whole brain pipeline is reused unchanged.
// Event payloads are pinned byte-for-byte to aion/src/aion/deck/protocol.py
// (host gate: test/test_deck.cpp).
//
// RAM: UnoHud 160 B, FrameDecoder 262 B, 4x JoyAxis + 2x RawAxisStream
// < 100 B — comfortably inside the ATmega328P's 2 KB.
#include <Arduino.h>
#include <Adafruit_GFX.h>
#include <Adafruit_ST7735.h>
#include "cyclops_shared.h"
#include "cycluno.h"
#include "joynav.h"
#include "deck.h"

// ---- display: 128x128 SPI TFT -----------------------------------------
// Target: common 1.44 in ST7735 128x128 module. RES is held high externally
// (3.3 V through 10 kOhm); it deliberately does not consume an Uno pin.
// Hardware SPI on Uno: D11=MOSI, D13=SCK.
#define PIN_TFT_CS 10
#define PIN_TFT_DC 9
static Adafruit_ST7735 tft(PIN_TFT_CS, PIN_TFT_DC, -1);

#define PIN_JOY1_Y A0
#define PIN_JOY1_X A1
#define PIN_JOY2_Y A2
#define PIN_JOY2_X A3
#define PIN_BTN_A 4
#define PIN_BTN_B 5
#define PIN_LED_REC 6
#define PIN_LED_LINK 7
#define PIN_BTN_J2 8

// D9/D10/D11/D13 are TFT SPI/control. Face controls move accordingly.
#define PIN_BTN_MODE 2
#define PIN_BTN_X 3
#define PIN_BTN_Y 12
// D13 is SPI clock, so it cannot be used as a mode LED.
#define PIN_LED_MODE A4

// Set to 1 if a stick direction feels flipped for your module's mounting.
#define JOY_FLIP_Y 0
#define JOY_FLIP_X 0

static cycluno::UnoHud hud;
static cycluno::JoyAxis joy1_y, joy1_x, joy2_y, joy2_x;
static cycluno::RawAxisStream raw2_x, raw2_y;
static bool app_mode = false;

static void on_frame(uint8_t type, const uint8_t* p, size_t n, void* ctx);
static cyclops::FrameDecoder dec(on_frame, nullptr);

// ---- outgoing ---------------------------------------------------------
static void send_frame(uint8_t type, const uint8_t* payload, size_t n) {
    uint8_t buf[96];  // status/cmd/input frames only — audio never originates here
    size_t k = cyclops::encode_frame(type, payload, n, buf, sizeof(buf));
    if (k) Serial.write(buf, k);
}

static void send_cmd(uint8_t act) {
    char payload[32];
    int n = snprintf(payload, sizeof(payload), "{\"a\":%u,\"arg\":\"\"}", act);
    send_frame(cyclops::MSG_CMD, (const uint8_t*)payload, (size_t)n);
}

static void send_input(uint8_t src, uint8_t code, int16_t val) {
    uint8_t p[4];
    cycluno::pack_input_event(src, code, val, p);
    send_frame(cyclops::MSG_INPUT_EVENT, p, 4);
}

// ---- incoming ---------------------------------------------------------
static unsigned long last_rx_ms = 0;

static void on_frame(uint8_t type, const uint8_t* p, size_t n, void*) {
    last_rx_ms = millis();
    char tmp[64];  // HUD rows hold 21 chars; clamp the JSON payload hard
    if (n >= sizeof(tmp)) n = sizeof(tmp) - 1;
    memcpy(tmp, p, n); tmp[n] = 0;
    if (type == cyclops::MSG_DISPLAY_CMD || type == cyclops::MSG_NOTE) {
        hud.apply_display_cmd(tmp);
    }
}

// ---- input ------------------------------------------------------------
// active-low buttons through DebouncedButton (deck.h): +1 press, -1 release
static cycluno::DebouncedButton btn_a, btn_b, btn_j2, btn_x, btn_y, btn_mode;

static int8_t edge(uint8_t pin, cycluno::DebouncedButton& b, unsigned long now) {
    return b.update(digitalRead(pin) == LOW, now);
}

static uint16_t joy_avg(uint8_t pin) {
    uint16_t acc = 0;
    for (uint8_t i = 0; i < 8; ++i) { acc += analogRead(pin); delay(2); }
    return acc / 8;
}

// forward a button's press+release in APP mode, press-only intent in AION
static void fwd_btn(int8_t e, uint8_t code) {
    if (e == 0) return;
    if (app_mode || e > 0) send_input(cycluno::SRC_BTN, code, e > 0 ? 1 : 0);
}

static void set_mode(bool app) {
    app_mode = app;
    digitalWrite(PIN_LED_MODE, app ? HIGH : LOW);
    send_input(cycluno::SRC_MODE, 0, app ? cycluno::MODE_APP : cycluno::MODE_AION);
    hud.toast(app ? "APP PAD" : "AION");
}

// ---- render sink -------------------------------------------------------
// GFX built-in font is 6x8. The 21-column x 16-row HUD occupies 126x128 px.
struct TftSink : cycluno::RowSink {
    void row(uint8_t idx, const char* text) override {
        char line[cycluno::COLS + 1];
        uint8_t i = 0;
        while (text[i] && i < cycluno::COLS) { line[i] = text[i]; ++i; }
        while (i < cycluno::COLS) line[i++] = ' ';
        line[cycluno::COLS] = 0;
        tft.fillRect(0, idx * 8, cycluno::COLS * 6, 8, ST77XX_BLACK);
        tft.setCursor(0, idx * 8);
        tft.print(line);
    }
};
static TftSink sink;

static void rec_led(bool on) { digitalWrite(PIN_LED_REC, on ? HIGH : LOW); }

void setup() {
    Serial.begin(115200);
    tft.initR(INITR_144GREENTAB);
    tft.setRotation(0);
    tft.fillScreen(ST77XX_BLACK);
    tft.setTextWrap(false);
    tft.setTextSize(1);
    tft.setTextColor(ST77XX_WHITE, ST77XX_BLACK);

    pinMode(PIN_BTN_A, INPUT_PULLUP);
    pinMode(PIN_BTN_B, INPUT_PULLUP);
    pinMode(PIN_BTN_J2, INPUT_PULLUP);
    pinMode(PIN_BTN_MODE, INPUT_PULLUP);
    pinMode(PIN_BTN_X, INPUT_PULLUP);
    pinMode(PIN_BTN_Y, INPUT_PULLUP);
    pinMode(PIN_LED_REC, OUTPUT);
    pinMode(PIN_LED_LINK, OUTPUT);
    pinMode(PIN_LED_MODE, OUTPUT);


    // sticks must be at rest during boot: their reading becomes the center
    joy1_y.calibrate(joy_avg(PIN_JOY1_Y));
    joy1_x.calibrate(joy_avg(PIN_JOY1_X));
    joy2_y.calibrate(joy_avg(PIN_JOY2_Y));
    joy2_x.calibrate(joy_avg(PIN_JOY2_X));
    raw2_x.calibrate(joy_avg(PIN_JOY2_X));
    raw2_y.calibrate(joy_avg(PIN_JOY2_Y));

    hud.send_cmd = send_cmd;
    hud.on_rec_led = rec_led;
    hud.init();
    hud.render(sink);
}

void loop() {
    // serial in -> decoder -> hud
    while (Serial.available()) dec.push((uint8_t)Serial.read());

    bool moved = false;
    unsigned long now = millis();

    // ---- joy1 + A/B: local HUD in AION mode, gamepad buttons in APP mode
    int8_t eA = edge(PIN_BTN_A, btn_a, now);
    int8_t eB = edge(PIN_BTN_B, btn_b, now);
    int8_t dy1 = joy1_y.update(analogRead(PIN_JOY1_Y), now);
    static int8_t x1_prev = 0;
    joy1_x.update(analogRead(PIN_JOY1_X), now);
    int8_t x1h = joy1_x.held();
    if (JOY_FLIP_X) x1h = -x1h;
    if (!app_mode) {
        if (dy1) { hud.on_wheel(JOY_FLIP_Y ? -dy1 : dy1); moved = true; }
        // X is edge-only: one action per flick, never auto-repeat (holding
        // the stick right must not machine-gun REC toggles).
        if (x1h != 0 && x1h != x1_prev) {
            if (x1h > 0) hud.on_btn_a(); else hud.on_btn_b();
            moved = true;
        }
        if (eA > 0) { hud.on_btn_a(); moved = true; }
        if (eB > 0) { hud.on_btn_b(); moved = true; }
    } else {
        fwd_btn(eA, cycluno::DBTN_A);
        fwd_btn(eB, cycluno::DBTN_B);
    }
    x1_prev = x1h;

    // ---- joy2: nav steps in AION mode, raw axis stream in APP mode
    if (!app_mode) {
        int8_t dy2 = joy2_y.update(analogRead(PIN_JOY2_Y), now);
        int8_t dx2 = joy2_x.update(analogRead(PIN_JOY2_X), now);
        if (JOY_FLIP_Y) dy2 = -dy2;
        if (JOY_FLIP_X) dx2 = -dx2;
        if (dy2) send_input(cycluno::SRC_JOY2, cycluno::CODE_STEP_Y, dy2);
        if (dx2) send_input(cycluno::SRC_JOY2, cycluno::CODE_STEP_X, dx2);
    } else {
        int16_t v;
        if (raw2_x.update(analogRead(PIN_JOY2_X), now, v))
            send_input(cycluno::SRC_JOY2, cycluno::CODE_RAW_X, JOY_FLIP_X ? -v : v);
        if (raw2_y.update(analogRead(PIN_JOY2_Y), now, v))
            send_input(cycluno::SRC_JOY2, cycluno::CODE_RAW_Y, JOY_FLIP_Y ? -v : v);
    }

    // ---- face buttons: J2 stick click, X, Y
    fwd_btn(edge(PIN_BTN_J2, btn_j2, now), cycluno::DBTN_J2);
    fwd_btn(edge(PIN_BTN_X, btn_x, now), cycluno::DBTN_X);
    fwd_btn(edge(PIN_BTN_Y, btn_y, now), cycluno::DBTN_Y);

    // ---- MODE button: toggle personalities (never forwarded as a button)
    if (edge(PIN_BTN_MODE, btn_mode, now) > 0) { set_mode(!app_mode); moved = true; }

    // link LED: lit while frames arrived within the last 2 s
    digitalWrite(PIN_LED_LINK, (millis() - last_rx_ms < 2000) ? HIGH : LOW);

    // 1 Hz: toast decay + status frame out
    static unsigned long last_tick = 0;
    bool dirty = false;
    if (millis() - last_tick >= 1000) {
        last_tick = millis();
        dirty = hud.tick();
        char st[48];
        int n = hud.status_json(st, sizeof(st));
        send_frame(cyclops::MSG_STATUS, (const uint8_t*)st, (size_t)n);
    }

    // redraw on any input or decayed toast
    static unsigned long last_draw = 0;
    if ((dirty || moved || millis() - last_draw > 250)) {
        hud.render(sink);
        last_draw = millis();
    }
    delay(5);
}

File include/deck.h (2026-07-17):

// Deck — CyclUno as aion's physical console: second stick, extra buttons,
// and a mode switch.
//
// Two modes, toggled by the MODE button (D2):
//   AION: joy1 + A/B drive the local HUD as before; joy2, X/Y and the face
//         buttons are forwarded to the host as MSG_INPUT_EVENT frames — aion
//         turns them into navigation Intents.
//   APP:  local HUD input is suspended; joy2 raw axes stream to the host
//         (which exposes them as a Linux uinput gamepad, "CyclUno Pad"), and
//         every face button (A/B/X/Y/J2) forwards press AND release.
//
// INPUT_EVENT payload (4 bytes, little-endian int16 value), kept in lockstep
// with aion/src/aion/deck/protocol.py:
//   src:  0 JOY1 · 1 JOY2 · 2 (was WHEEL) · 3 BTN · 4 MODE
//   joy codes:   0 step-x ±1 · 1 step-y ±1 · 2 raw-x · 3 raw-y (centered)
//   btn codes:   0 A · 1 B · 2 J2-SW · 3 (was WHEEL-SW) · 4 MODE · 5 X · 6 Y
//                (val 1=down 0=up)
//   mode codes:  0 (val 0=AION 1=APP), sent on every toggle
//
// Everything here is pure logic (no Arduino headers) so it is host-testable:
// test_deck.cpp feeds pin levels / readings and asserts emitted events.
// RAM gates: sizeof(RawAxisStream) tiny.
#pragma once
#include <stdint.h>

namespace cycluno {

// ---- event enums (mirror protocol.py) ------------------------------------
// NOTE: the wheel (src 2, btn 3) was removed; its numeric codes are left
// unused on purpose so existing aion pairing stays byte-compatible.
static const uint8_t SRC_JOY1 = 0, SRC_JOY2 = 1, SRC_WHEEL = 2,
                     SRC_BTN = 3, SRC_MODE = 4;
static const uint8_t CODE_STEP_X = 0, CODE_STEP_Y = 1,
                     CODE_RAW_X = 2, CODE_RAW_Y = 3;
static const uint8_t DBTN_A = 0, DBTN_B = 1, DBTN_J2 = 2, DBTN_WHEEL = 3,
                     DBTN_MODE = 4, DBTN_X = 5, DBTN_Y = 6;
static const uint8_t MODE_AION = 0, MODE_APP = 1;

// Pack one input event into a 4-byte payload. Buffer must hold 4 bytes.
inline void pack_input_event(uint8_t src, uint8_t code, int16_t val,
                             uint8_t* out) {
    out[0] = src;
    out[1] = code;
    out[2] = (uint8_t)(val & 0xFF);
    out[3] = (uint8_t)((val >> 8) & 0xFF);
}

// ---- debounced button -------------------------------------------------------
// The old edge() helper claimed "debounced" but only tracked level flips: any
// contact bounce spanning two loop iterations double-fired (machine-gun REC
// toggles). Real debounce: a level change is accepted only once the raw input
// has been stable for SETTLE_MS. Sub-settle glitches emit nothing.
class DebouncedButton {
public:
    static const uint16_t SETTLE_MS = 20;

    // Feed the raw level (true = pressed) + clock.
    // Returns +1 on a settled press, -1 on a settled release, 0 otherwise.
    int8_t update(bool pressed, unsigned long now_ms) {
        if (pressed != raw_) { raw_ = pressed; settle_ms_ = now_ms; }
        if (raw_ != state_ &&
            (long)(now_ms - settle_ms_) >= (long)SETTLE_MS) {  // wrap-safe
            state_ = raw_;
            return state_ ? 1 : -1;
        }
        return 0;
    }

    bool pressed() const { return state_; }

private:
    bool raw_ = false;
    bool state_ = false;
    unsigned long settle_ms_ = 0;
};

// ---- APP-mode raw axis streaming -------------------------------------------
// Decides when a raw axis reading is worth a frame: on meaningful change
// (> STEP counts) or on returning to center, rate-limited to MIN_INTERVAL_MS.
// Keeps serial traffic low so the Uno's loop never starves.
class RawAxisStream {
public:
    static const int16_t STEP = 8;              // ADC counts of change to send
    static const uint16_t MIN_INTERVAL_MS = 30; // max ~33 frames/s per axis

    void calibrate(uint16_t raw_center) { center_ = (int16_t)raw_center; }

    // Returns true when `out_val` should be sent (centered value).
    bool update(uint16_t raw, unsigned long now_ms, int16_t& out_val) {
        int16_t v = (int16_t)raw - center_;
        if ((long)(now_ms - next_ms_) < 0) return false;
        int16_t d = (int16_t)(v - last_sent_);
        if (d < 0) d = (int16_t)-d;
        bool centered_now = (v > -STEP && v < STEP);
        bool was_off = (last_sent_ <= -STEP || last_sent_ >= STEP);
        if (d >= STEP || (centered_now && was_off)) {
            last_sent_ = centered_now ? 0 : v;
            out_val = last_sent_;
            next_ms_ = now_ms + MIN_INTERVAL_MS;
            return true;
        }
        return false;
    }

private:
    int16_t center_ = 512;
    int16_t last_sent_ = 0;
    unsigned long next_ms_ = 0;
};

}  // namespace cycluno

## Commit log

2026-07-13 feat: CyclUno standalone firmware — HW-504 joystick navigation
    Extracted from cyclops feat/cycluno (firmware side only; brain stays in
    cyclops). Input scheme replaced: rotary encoder + two buttons out, HW-504
    analog joystick + one button in.
    - include/joynav.h: JoyAxis — raw ADC to discrete nav steps. Dead zone,
    immediate step on threshold crossing, auto-repeat (350 ms then 140 ms),
    re-arm on release, boot-time center calibration. Pure logic, no Arduino
    deps, host-tested (test_joynav.cpp) incl. sizeof <= 16 B gate.
    - src/main.cpp: Y axis drives on_wheel; X axis edge-only (one action per
    flick, never auto-repeat — holding right must not machine-gun REC):
    right = A, left = B.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
    [main.cpp]
2026-07-14 feat: deck edition — second stick, KY-040 wheel, mode switch for aion
    CyclUno grows into aion's control deck while keeping its cyclops dev-unit
    role intact:
    - deck.h (host-testable, no Arduino deps): INPUT_EVENT payload packing
    pinned byte-for-byte to aion's deck/protocol.py, KY-040 quadrature
    decoder, APP-mode raw-axis streaming with rate limit + recenter
    - main.cpp: joy2 on A2/A3+D8, encoder on the D2/D3 interrupt pins (ISR,
    no missed detents) + SW D9, MODE D10, X D11, Y D12, APP LED D13
    - AION mode: joy1+A/B keep driving the local HUD; wheel/joy2/X/Y forward
    to the host as MSG_INPUT_EVENT for cockpit navigation
    - APP mode: local HUD input suspended; joy2 streams raw axes, all f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
    [deck.h, main.cpp]
2026-07-14 docs: wiring guide rewrite + SVG diagrams
    - docs/WIRING.md: BOM, pin map, incremental assembly order (each step
    leaves a working unit), wiring rules, smoke test, troubleshooting table
    - docs/img/deck-wiring.svg: full schematic — Uno pinout with color-coded
    nets per module, power rails, routing for the crossing nets
    - docs/img/deck-layout.svg: console ergonomics (sticks/wheel/buttons/LEDs)
    - README: wiring section now embeds the diagrams and links the guide
2026-07-14 docs(wiring): per-pin fan-out table for breadboard-less builds
    One wire per signal pin; only 5V (1 socket, 4 loads) and GND (3 sockets,
    10 returns) branch — includes suggested daisy-chains and the note that
    stick/wheel clicks return through their module GND, so only the four
    standalone buttons need a GND leg.
2026-07-14 docs(wiring): I2C notes — pullups onboard, A4/A5=SDA/SCL same net, 400kHz length limit, bus expansion
2026-07-14 feat(display): 128x128 OLED — u8x8 driver, 16-row HUD
    Swap SSD1306Ascii for u8g2's U8x8 text mode (still zero framebuffer, so
    the 2 KB RAM discipline holds — build lands at 72% RAM, HUD 264 B):
    - default panel: SSD1327 128x128 (Waveshare-style); SH1107 128x128 and
    legacy SSD1306 128x64/32 selectable via -DDISPLAY_* build flags
    - HUD grid grows to 16 rows x 16 cols: HOME now shows banner + the last
    12 notes + hints, NOTES scrolls a 15-row window, MENU clears unused rows
    (every render writes all rows so nothing lingers)
    - MAX_NOTES 4 -> 12; sink pads rows to full width
    - docs: WIRING.md BOM/pin map/flash flags/troubleshooting for the new
    panel, README quick map, wiring+layout SVGs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
    [main.cpp]
2026-07-14 feat(display): finalize 128x128 as the only panel — drop 128x32 legacy path
    - remove DISPLAY_SSD1306_128X32 branch from display selection in src/main.cpp
    - legacy now means 128x64 only (clips to top 8 rows); HUD built for 128x128
    - WIRING.md: drop the 128x32 make-flash line, mark 128x128 as the target panel
    - fold in the already-128x128-correct deck-wiring.svg rework + deck-power.svg
    [main.cpp]
2026-07-14 feat: remove rotary encoder (KY-040) from the deck
    - src/main.cpp: drop PIN_ENC_*, PIN_BTN_WHEEL, wheel ISR + take_wheel,
    wheel INPUT_EVENT send, wheel-click button forward. Local HUD nav now
    joystick-only (on_wheel kept, fed by joy1).
    - include/deck.h: drop CODE_WHEEL_STEP + QuadDecoder class; keep SRC_WHEEL
    and DBTN_WHEEL constants at their byte ids so aion pairing stays compatible.
    - test/test_deck.cpp: drop wheel pack + quadrature tests + RAM sizeof.
    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
2026-07-14 docs(wiring): document the 128x128 OLED's RES/DC/CS/BL pins
    The firmware drives the panel over I2C (U8X8_PIN_NONE), so only VCC/GND/
    SDA/SCL reach the Uno. Added an OLED wiring-notes section covering what
    to do with the four extra breakout pins: RES->VCC, DC->GND, CS->GND
    (I2C boards), and BL as a current-limited LED (150-220R to 5V). Plus a
    troubleshooting row for 'dark / won't boot' tied to the RES/DC/CS ties.
2026-07-15 docs: expand WIRING.md with deep 128x128 OLED section
    - Controller comparison table (SSD1327/SH1107/SSD1306)
    - RES/DC/CS strapping depth, pull-up verification
    - SH1107 vs SSD1327 identification guide
    - U8X8 address gotcha (7-bit vs 8-bit shift)
    - I2C scanner sketch, OLED power budget
    - 6 new troubleshooting entries for common OLED failures
2026-07-16 feat(cad): CyclUno enclosure v0.2 — base + standoffs + screw-on lid
    Parametric FreeCAD CSG (build_cycluno_case_v02.py):
    - Base: 94x66x34mm, 2mm walls, 90x62x30 cavity, USB slot
    - 4 corner standoffs (M3 tap holes), inset 10mm
    - Lid: 94x66x4mm, 4 clearance holes + countersink
    Saved: cad/cycluno_case/CyclUnoCase_v02.FCStd
    Host gate + compile gate green (make test / make build).
    [CyclUnoCase_v02.FCStd]
2026-07-16 feat(cad): form-factor spec + CyclUnoCase v0.3 (Palm Deck Tier B)
    docs/FORMFACTOR.md: design thesis from aion nav model (13-workspace
    one-handed dual-thumb deck). Tier A Palm Deck / Tier B Dockable Slab.
    v0.3: raked offset thumbsticks (not collinear), MODE rocker slot on
    top edge, OLED as top-center status compass, 4-button diamond,
    rounded grip fillet, 4 M3 standoffs + screw-on lid.
    Built headless, saved cad/cycluno_case/CyclUnoCase_v03.FCStd.
    [CyclUnoCase_v03.FCStd]
2026-07-16 feat(cad): CyclUnoCase v0.4 Palm Deck (hand-envelope derived) + honest v0.3 note
    v0.4: layout DERIVED from palm envelope (95x105mm avg), not a
    rectangle. Thumb-pads at 30%/70% width, near-wrist (y=34%) ->
    offset symmetric sticks leaining inward 15deg. OLED at upper sight-line
    (y=74%). 4-btn diamond in right-thumb arc. MODE detent rocker on
    index edge. 4x M3 standoffs + screw-on lid. 114cm3 shell.
    Fix: R=10 fillet had collapsed 2.5mm walls (solid 398cm3) ->
    safe R=2.0 < wall.
    FORMFACTOR.md: flags v0.3 as dev-enclosure (coordinate-placed,
    NOT ergo-derived); v0.4 metrics are anthropometric AVG and
    parameterized for real hand measures.
    [CyclUnoCase_v04.FCStd]
2026-07-16 feat(cad): CyclUnoCase v0.5 - reliable contoured shell + real-component holes
    Build is ROBUST booleans only (no flaky loft): rounded-box shell
    (R=2 fillet) hollowed to a pocket, floor capped.
    Holes sized to RESEARCHED real parts:
    - joystick: counterbored shaft (R5.5) + chamfer bezel, 12deg lean
    - OLED: recessed 30x40 pocket + 20x33 glass window (128x128)
    - buttons: counterbored 6mm-foot holes + 2mm actuator through (diamond)
    - LEDs: 2.6mm holes
    - MODE: detent rocker slot + 3 detent dimples
    - Uno: 4x M3 standoffs at REAL Uno R3 hole spacing (68.6x53.4)
    - 2 swept thumb wells (sphere-cap recesses) at 30/70% width
    NOTE: loft-based organic contour failed reliably (makeLoft null on
    near-degenerat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
    [CyclUnoCase_v05.FCStd]
2026-07-17 feat: support SPI 128x128 TFT display
2026-07-17 fix: correct stale pin/display comments, honest CAD evolution map
    MODE/X/APP-LED comments still cited pre-TFT pins (D10/D11/D13); real
    pins are D2/D3/A4. cycluno.h still described an SSD1306 OLED and main.cpp
    budgeted a QuadDecoder that no longer exists. FORMFACTOR CAD map now
    records v0.5-v0.7 including why v0.6 never produced an FCStd.
    [deck.h, main.cpp]
2026-07-17 feat(cad): CyclUnoCase v0.7 — TFT-era Palm Deck, working boolean pipeline
    v0.6 (archived here for lineage) never produced an FCStd: it lofted
    faces so Part returned a Shell and every boolean threw Null shape, cut
    its layout in the wrong quadrant (origin-centered loft vs 0..W coords),
    fed radians to the degrees-based Rotation() so stick rake was ~0.2 deg,
    placed the button diamond inside the joy2 thumb well rim, kept the old
    OLED pocket, and never called saveAs.
    v0.7 fixes all of that and moves the design to the SPI TFT era:
    - solid loft (wires + solid=True) hollowed by cutting the wall-offset
    inner solid; lid loft uses an interpolated z=5 section
    - offset thumbsticks per FORMFACTOR rule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
    [Arduino_Uno.step, CyclUnoCase_v07.FCStd, LED_D5.0mm.step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]
2026-07-17 chore(cad): commit re-saved v03 FCStd
    Binary re-save from a FreeCAD session; geometry still regenerable from
    build_cycluno_case_v03.py.
    [CyclUnoCase_v03.FCStd]
2026-07-17 feat: real time-based button debounce
    edge() claimed "debounced" but only tracked level flips — contact
    bounce spanning two loop iterations double-fired (machine-gun REC
    toggles). DebouncedButton accepts a level change only after the raw
    input has been stable for 20 ms; sub-settle glitches emit nothing.
    Host-gated in test_deck.cpp (stable press, bouncy press/release,
    sub-settle spike). RAM 54.5% -> 56.0%.
    [deck.h, main.cpp]
2026-07-17 docs: fix stale D13 LED refs + garbled controls text in README
    APP-mode indicator moved to A4 when the SPI TFT claimed D13; the
    controls section still gated modes on D13 and had two mangled
    sentences from an earlier edit.
2026-07-17 feat(cad): CyclUnoCase v0.8 — final ergonomic deck, dims reconciled to pulled STEP models
    Real component measurements from cad/components/ STEP files:
    - tact switch 7.2x6.0x8.5 -> BTN_FOOT 7.2 (was 6.0)
    - LED 5.4 dia x14.1 -> hole R 2.8 (was 2.6)
    - 1x08 header 11.5 tall -> TFT pocket depth sized for header stack
    - Arduino STEP is partial connector model -> board stays datasheet 68.6x53.4
    Watertight manifold base 79.5cm3 + lid 40.7cm3, both valid.
    [Base_v08.stl, CyclUnoCase_v08.FCStd, Lid_v08.stl]
2026-07-17 fix(cad): CyclUnoCase v0.9 — proper centered lid mounting
    v0.8 reused the asymmetric Arduino drill pattern for lid screws (off-center,
    wrongly spaced, read as bottom holes). v0.9 adds 4 symmetric corner screw
    posts tapped in the base + counterbored through-holes in the lid.
    Holes form a centered rectangle: X 9/98 (9mm from each side, W=107),
    Y 9/102 (9mm from each side, D=111). Lid screws down from the top into
    floor posts that stop 5mm below the top face. Base 83.1cm3 watertight,
    lid 41.0cm3 valid.
    [Base_v09.stl, CyclUnoCase_v09.FCStd, Lid_v09.stl]
2026-07-17 fix(cad): CyclUnoCase v10 — correct split Tray + TopShell
    Previous versions had a single capped solid with pockets and an inverted lid.
    v10 splits into:
    - Tray: open-top floor + walls, 14mm tall, holds Arduino Uno on 4 standoffs
    (6mm) at the real drill pattern. USB-B + barrel-jack cutouts on the -X wall.
    - TopShell: ergonomic contoured palm-shaped upper half (lofted wires), open
    bottom, carries all controls: 2 raked joystick holes, 4-button diamond,
    2 LED holes (5.4mm real), TFT pocket sized for 11.5mm header stack,
    thumb wells, MODE slot.
    - Mounting: 4 symmetric corner screw bosses tapped in the tray; top shell has
    counterbored holes so screws go DOWNWARD from the top into the t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
    [CyclUnoCase_v10.FCStd, TopShell.stl, Tray.stl]
2026-07-17 docs: palm-deck research compendium (deep-research harvest)
    4 claims adversarially verified 3-0 (MSP1443 dims, 3.3V TTL logic IO,
    no documented hole pattern, 5V-tolerant VCC); ~20 more source-cited but
    unverified after the verify infra rate-limited twice. Ergonomics angle
    returned nothing citable — FORMFACTOR heuristics stay design priors.
2026-07-17 feat(cad): CyclUnoCase v11 — research-verified dims + MTS-103 MODE mount
    Folds docs/reference/palm-deck-research.md into the v10 split design:
    - TFT pocket for the real MSP1443 footprint (29.7 x 43.36 mm PCB,
    26.2 x 27.2 mm active area, both verified 3-0 against lcdwiki),
    mounted landscape so the pocket stays inside the shell top face;
    corner posts remain placeholders — vendor documents no hole pattern.
    - MODE selector is now an MTS-103 ON-OFF-ON toggle: M6 bushing hole,
    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
    [CyclUnoCase_v11.FCStd]

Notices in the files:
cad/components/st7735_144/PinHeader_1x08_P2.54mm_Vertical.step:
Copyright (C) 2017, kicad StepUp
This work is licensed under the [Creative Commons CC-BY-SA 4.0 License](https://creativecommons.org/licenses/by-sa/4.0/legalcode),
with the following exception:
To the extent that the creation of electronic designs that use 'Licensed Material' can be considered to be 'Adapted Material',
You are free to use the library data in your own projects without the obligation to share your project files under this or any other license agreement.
